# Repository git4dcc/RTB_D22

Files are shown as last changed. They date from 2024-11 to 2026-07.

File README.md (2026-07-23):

# RTB_D22




My Homebrew [D22](https://rtb4dcc.de/hardware/decoder/d22/) decoder is a double sided mobile decoder with Plux16 connector. The decoder is designed to integrate into the [RTB](https://rtb4dcc.de/concept/) digital control infrastructure.

<details>
<summary>See also</summary>

- [RTB_D12 - custom](/../../../../RTB_D12) (Fleischmann V100)
- [RTB_D13 - custom](/../../../../git4dcc/RTB_D13) (Minitrix coach)
- [RTB_D15 - custom](/../../../../git4dcc/RTB_D15) (Minitrix V160)
- [RTB_D16 - NEM651](/../../../../git4dcc/RTB_D16)
- [RTB_D20 - NEM651](/../../../../git4dcc/RTB_D20)
- [RTB_D21 - Next18](/../../../../git4dcc/RTB_D21)
- [RTB_D23 - NEM652](/../../../../git4dcc/RTB_D23)

</details>

<details>
<summary>User Guides</summary>

- User Guide - DE
- [User Guide - EN](https://rtb4dcc.de/rtb_decoder_reference_en/)

</details>

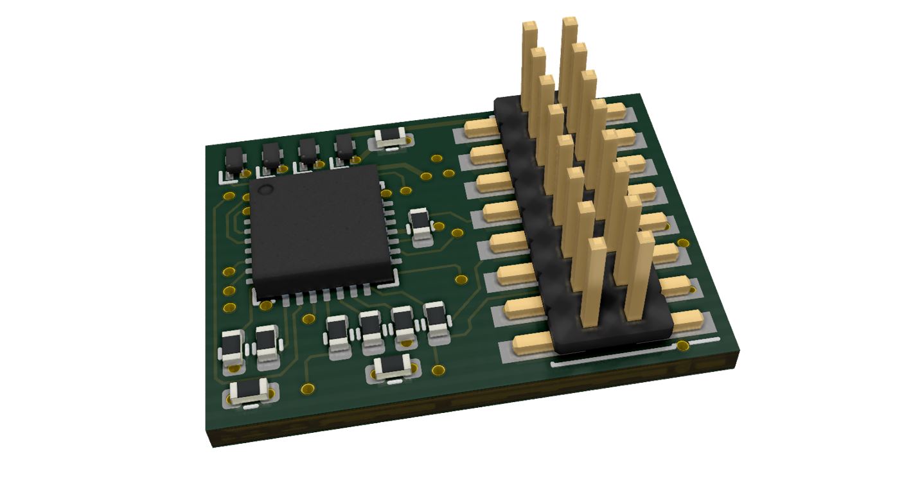
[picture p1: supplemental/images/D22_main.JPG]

<br>

## Decoder features,
- **Plux16** connector
- **DCC**
  - DCC-A automatic logon
  - DCC-R protocol extension
  - Service Mode Programming
- **Railcom**
  - Channel 1/2
  - POM, xPOM
  - DYN: Speed, QoS, Track-voltage, Motor-current, AUX-current, Temp, Distance travelled
- Double sided
- Dimension: 15 x 11 mm
- 7-20V track voltage
- heartbeat LED
- adjustable max motor current (default 300mA)
- adjustable max AUX current (default 500mA)
- over temp protection
- Function output: LF/LR (dimmable, 1.4kHz) open drain
- Function output: AUX1/AUX2 (dimmable, 1.4kHz) open drain
- Function output: AUX3/AUX4 logic level (3.3V) using LS A/B ports
- Function output: AUX5/AUX6 logic level (3.3V) or ZBCLK/ZBDAT (3.3V)
- optional external buffer capacitor
- <10mA idle power consumption
- Firmware update over main tracks via DCC-R protocol

# Hardware
The current PCB layout uses SMD footprints with 0.5mm pitch and 0402 parts. Reflow soldering is mandatory whereas handsoldering near to impossible.

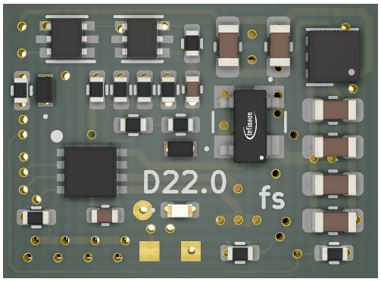
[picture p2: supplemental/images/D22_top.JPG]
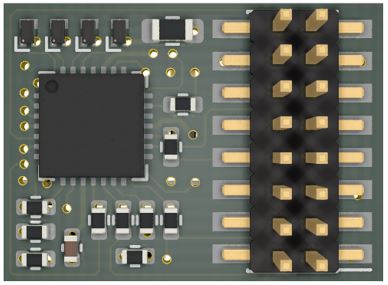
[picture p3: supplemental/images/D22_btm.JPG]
   

## PCB
- 6-layer PCB, FR4, 15 x 11 x 0.8mm (double sided)
- CPU: AVR64DD28
- Motor bridge: DRV8231

## Kicad
[Schematic](doc/D22_schematic.pdf) | [Layout](doc/D22_layout.pdf) | [Gerber](production)

<details>
<summary>Dependency</summary>
<br>

:yellow_circle: Requires my Kicad project library [RTB_SamacSys](https://github.com/git4dcc/RTB_SamacSys) in the same directory tree.

</details>

## Firmware
Filename structure: { **pcb** }{ **code** }{ **version** }.hex

Example: **D22F0001**.hex

| | Description |
| --- | --- |
| **pcb** | Name of matching hardware (**D22**) |
| **code** | Type of code contained (**R**=rom, **B**=bootloader, **F**=flash, **U**=bld update, **P**=UPDI factory code) |
| **version** | Release version (**####**) |

[Firmware files](firmware)

## UPDI
The fuse settings as well as the P-code (D22Pxxxx.hex) has to be installed by using UPDI.<br>
Connecting the decoder via its track pins to a 5V(DC) power supply will boot its CPU. This way, its easy to program the fuses and flash.

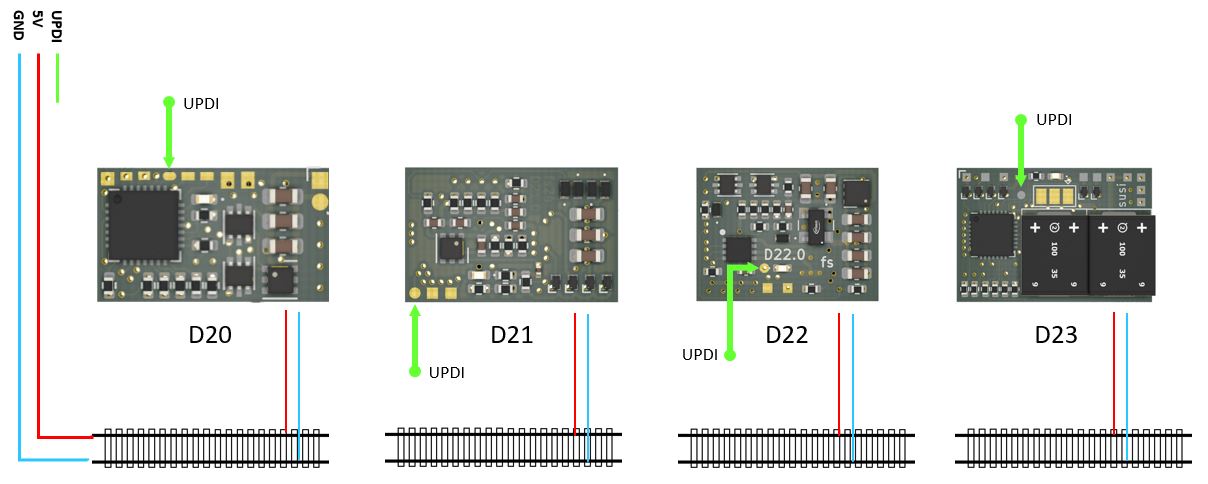
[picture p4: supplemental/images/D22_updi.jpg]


<details>
<summary>Details</summary>

| Fuse Setting | P-code Install |
| --- | --- |
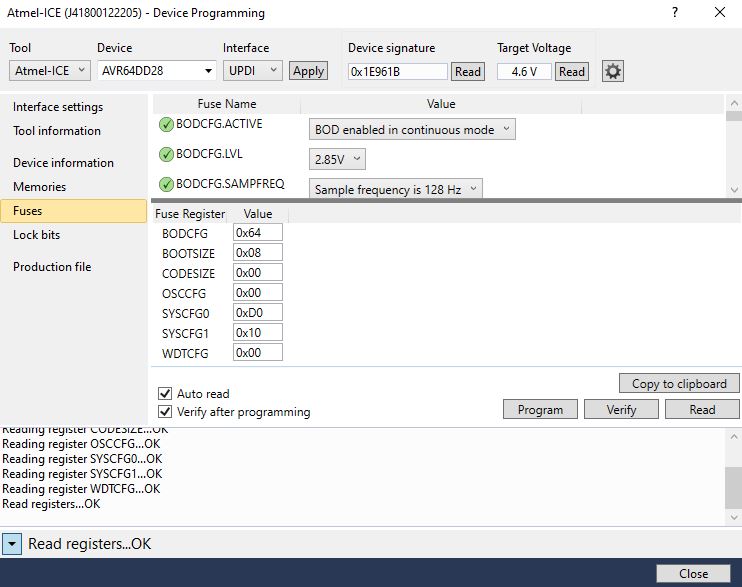
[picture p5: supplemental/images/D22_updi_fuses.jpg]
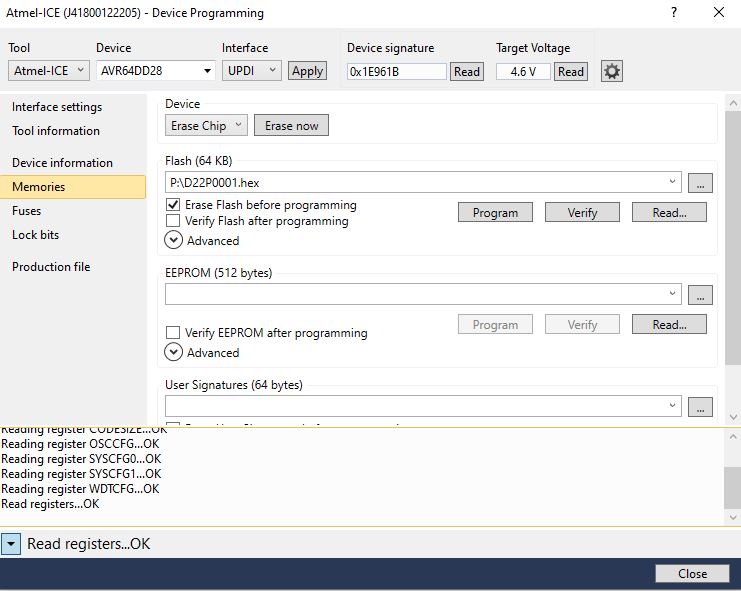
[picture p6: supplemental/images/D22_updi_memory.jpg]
|||

</details>

# Images
| top | bottom |
| --- | --- |
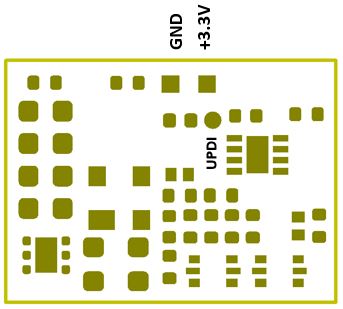
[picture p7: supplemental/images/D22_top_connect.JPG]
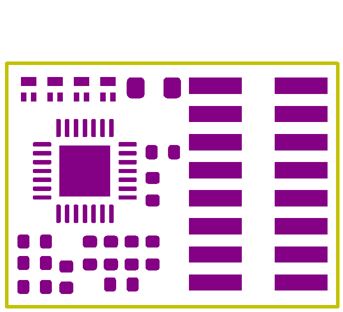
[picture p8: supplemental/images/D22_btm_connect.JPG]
|  |  |

# YouTube
Some YouTubes to see the D22 decoder in action.<br><br>
[](https://youtu.be/aH7pGpX5ZGo)
[](https://youtu.be/Ebl8b5DK1Gw)

This project is intended for hobby use only and is distributed in accordance with the Apache License 2.0 agreement.

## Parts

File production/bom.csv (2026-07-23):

Designator | Footprint | Quantity | Value | LCSC Part #
C1, C2 | 0603 | 2 | 10u/25V | C96446
C10, C8 | 0402 | 2 | 100n/50V | C307331
C3, C5 | 0603 | 2 | 22u/6V | C59461
C6 | 0402 | 1 | 1u/50V | C52923
D1, D2, D4 | SM5819L2TP | 3 | SM5819L2-TP | C6297199
D3 | 0402 | 1 | LED | C130724
D8 | BF998215 | 1 | BAS3007ARPPE6327HTSA1 | C6430958
IC1 | QFN-28-1EP_4x4mm_P0.4mm_EP2.3x2.3mm | 1 | AVR64DD28-I_STX | C5156221
IC2 | WSON-6-1EP_2x2mm_P0.65mm_EP1x1.6mm | 1 | NCP730BMT500TBG | C892822
IC3 | SON50P200X200X80-9N | 1 | DRV8231ADSGR | C5139865
IC4 | WSON-6-1EP_2x2mm_P0.65mm_EP1x1.6mm | 1 | NCP730BMT1500TBG | C892817
J1 | PinHeader_2x08_P1.27mm_Vertical_SMD | 1 | Conn_02x08_Counter_Clockwise
J2 | Solder 0.8 x 0.5 | 1 | Conn_01x01
Q1 | SOT-666 | 1 | BC847BDW1 | C455062
Q2 | SOT-666 | 1 | BC857BDW1 | C282521
Q3, Q4, Q5, Q6 | Diodes_DFN1006-3 | 4 | PMZB200UNEYL | C547292
R1, R15, R17, R2 | 0402 | 4 | 33k | C25779
R10, R9 | 0402 | 2 | 9.1k | C163450
R11, R12, R24, R5, R6 | 0402 | 5 | 10k | C25744
R13 | 0402 | 1 | 1k | C11702
R14, R7, R8 | 0402 | 3 | 220k | C25767
R16, R18 | 0402 | 2 | 12k | C25752
R19 | 0603 | 1 | 1 | C22936
R20 | 0402 | 1 | 47k | C25792
R21, R22 | 0402 | 2 | 470 | C25117
R23 | 0603 | 1 | 100 | C22775
R3 | 0402 | 1 | 3.3k | C25900
R4 | 0402 | 1 | 22 | C25092

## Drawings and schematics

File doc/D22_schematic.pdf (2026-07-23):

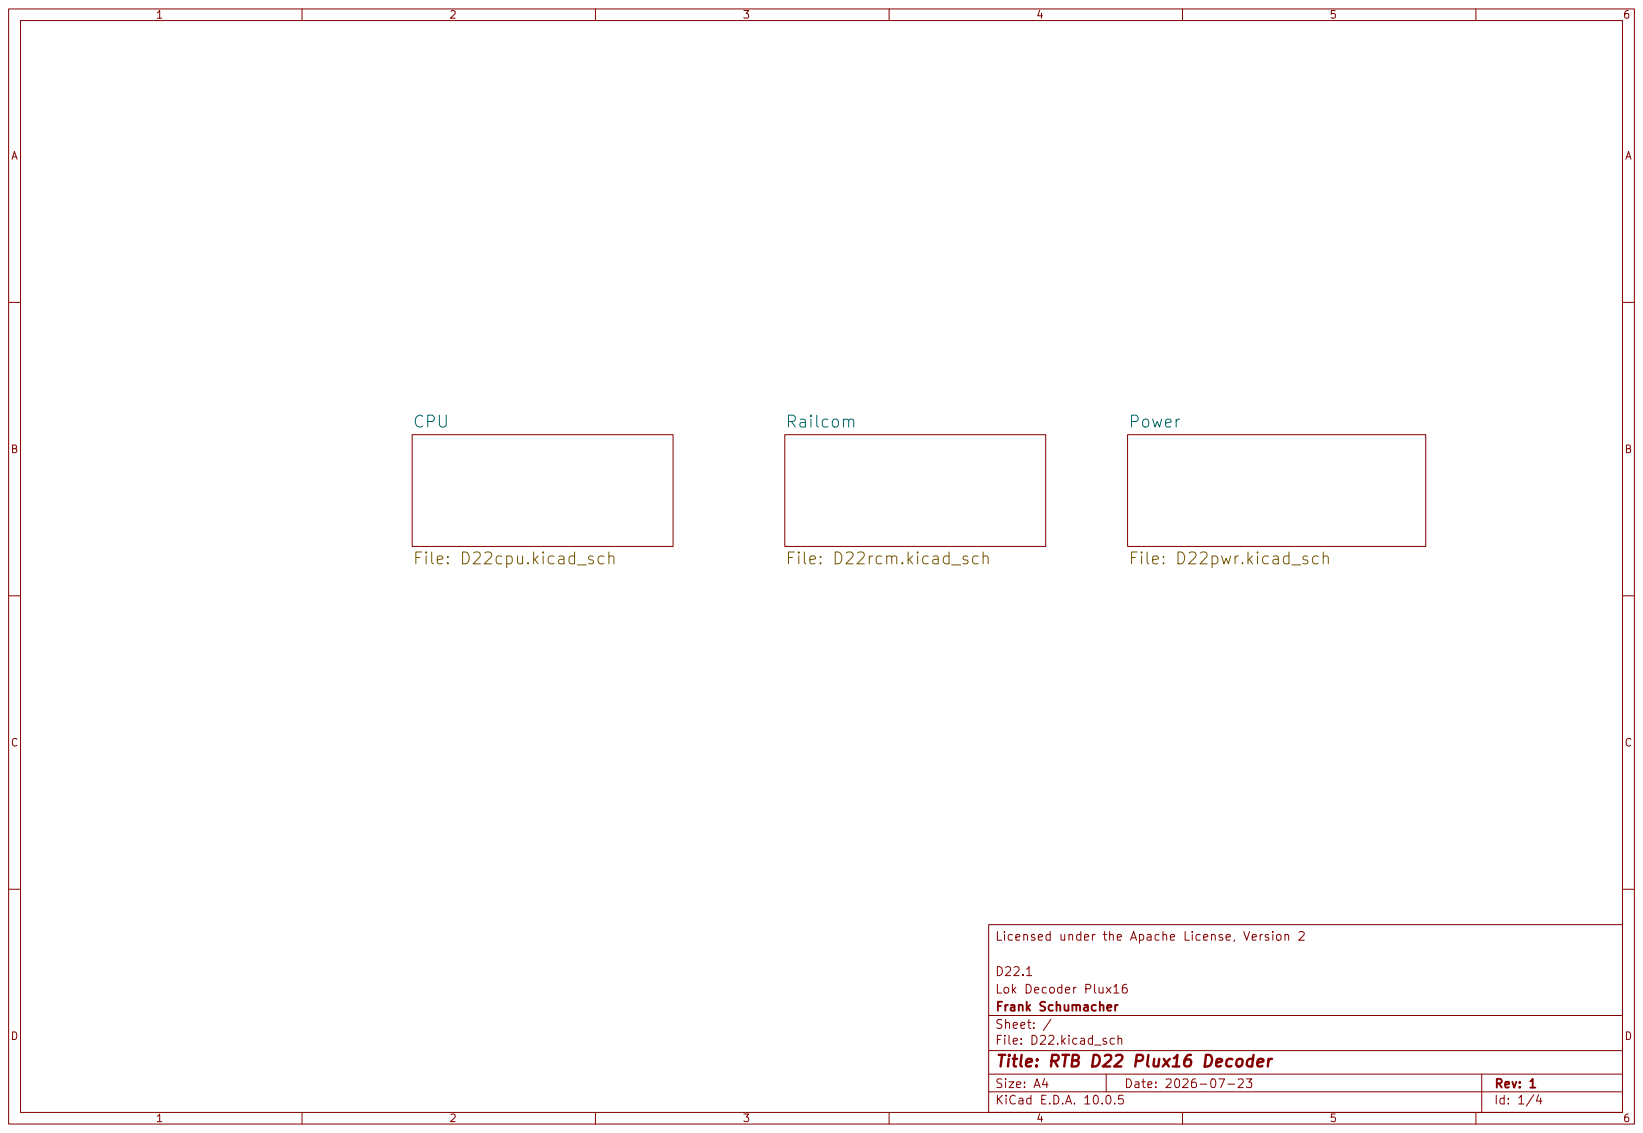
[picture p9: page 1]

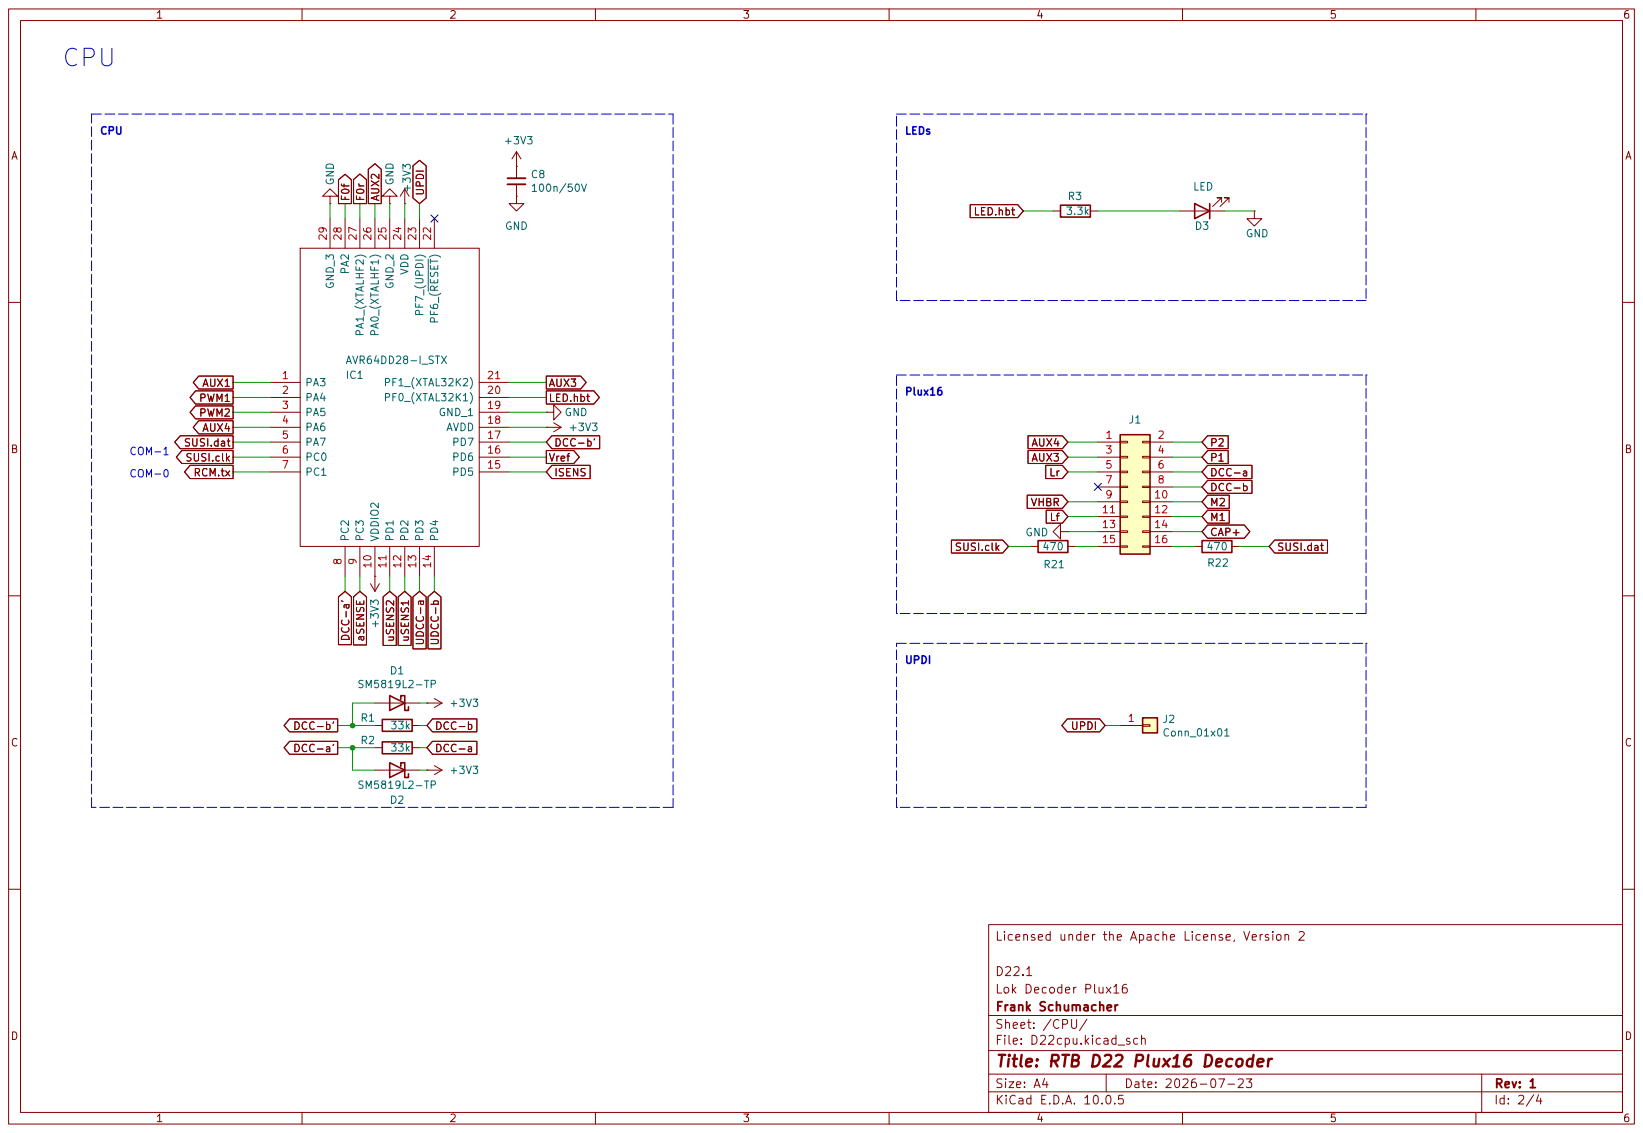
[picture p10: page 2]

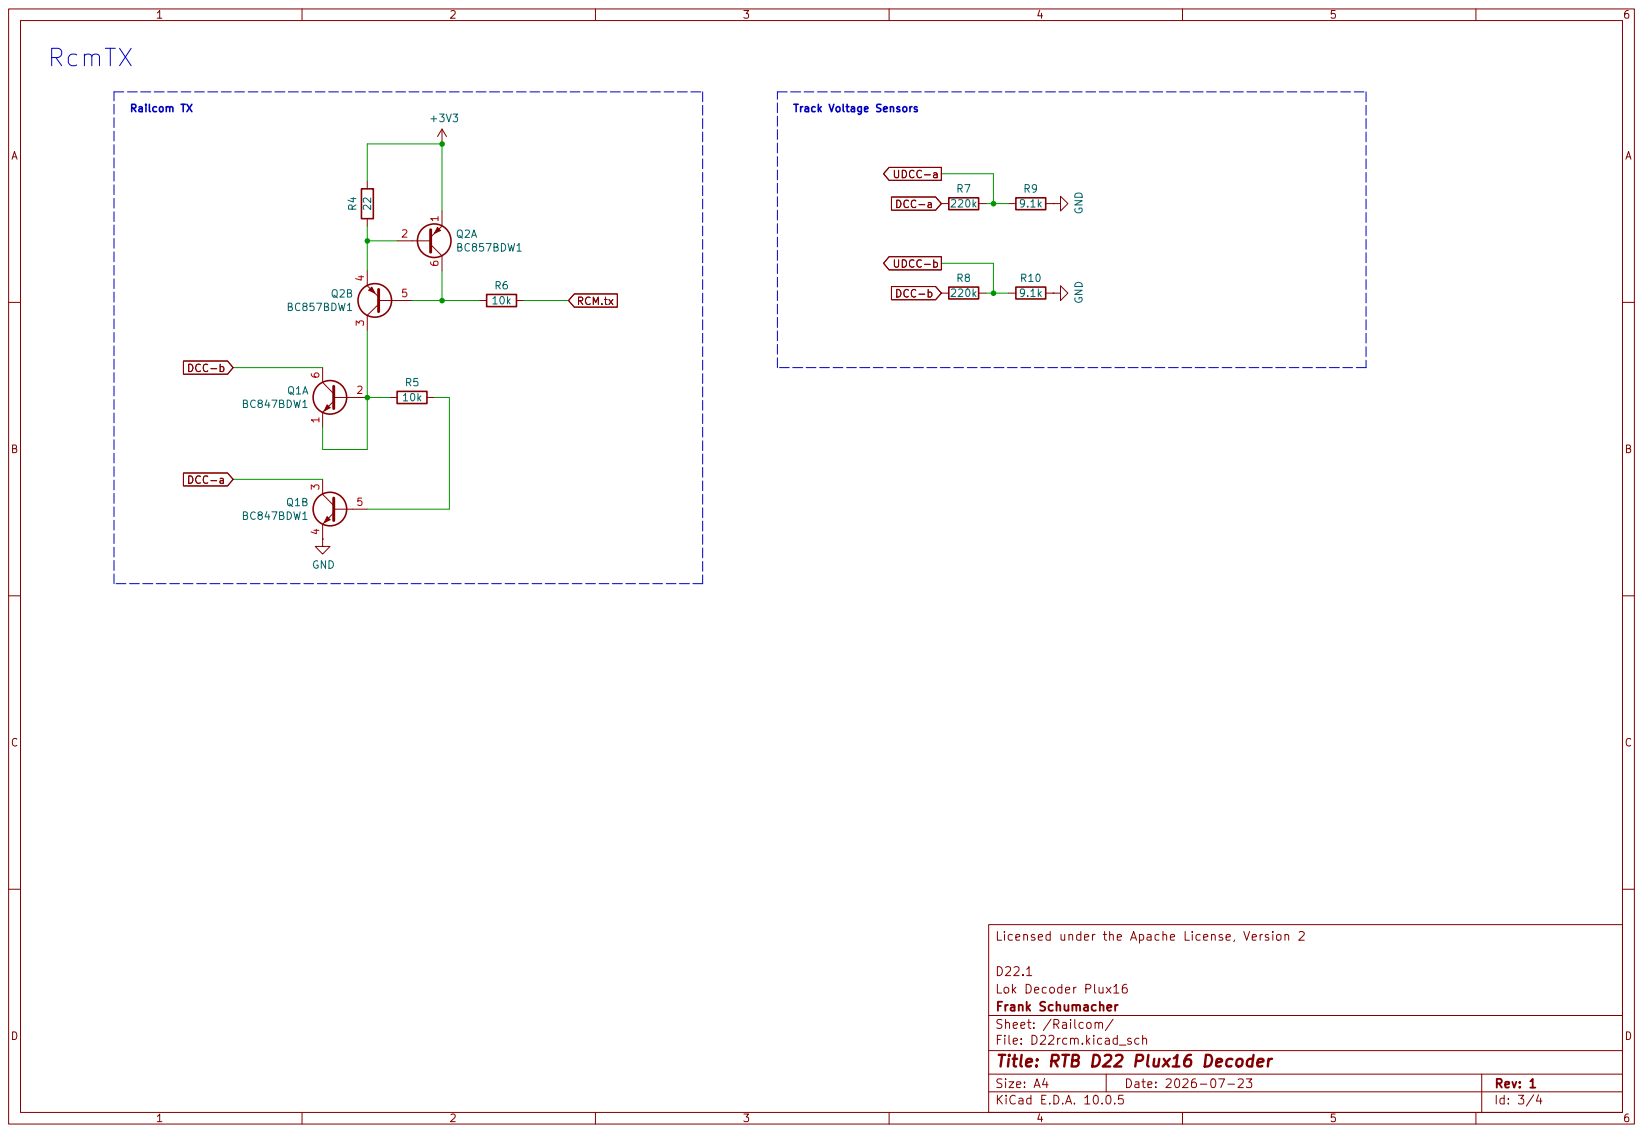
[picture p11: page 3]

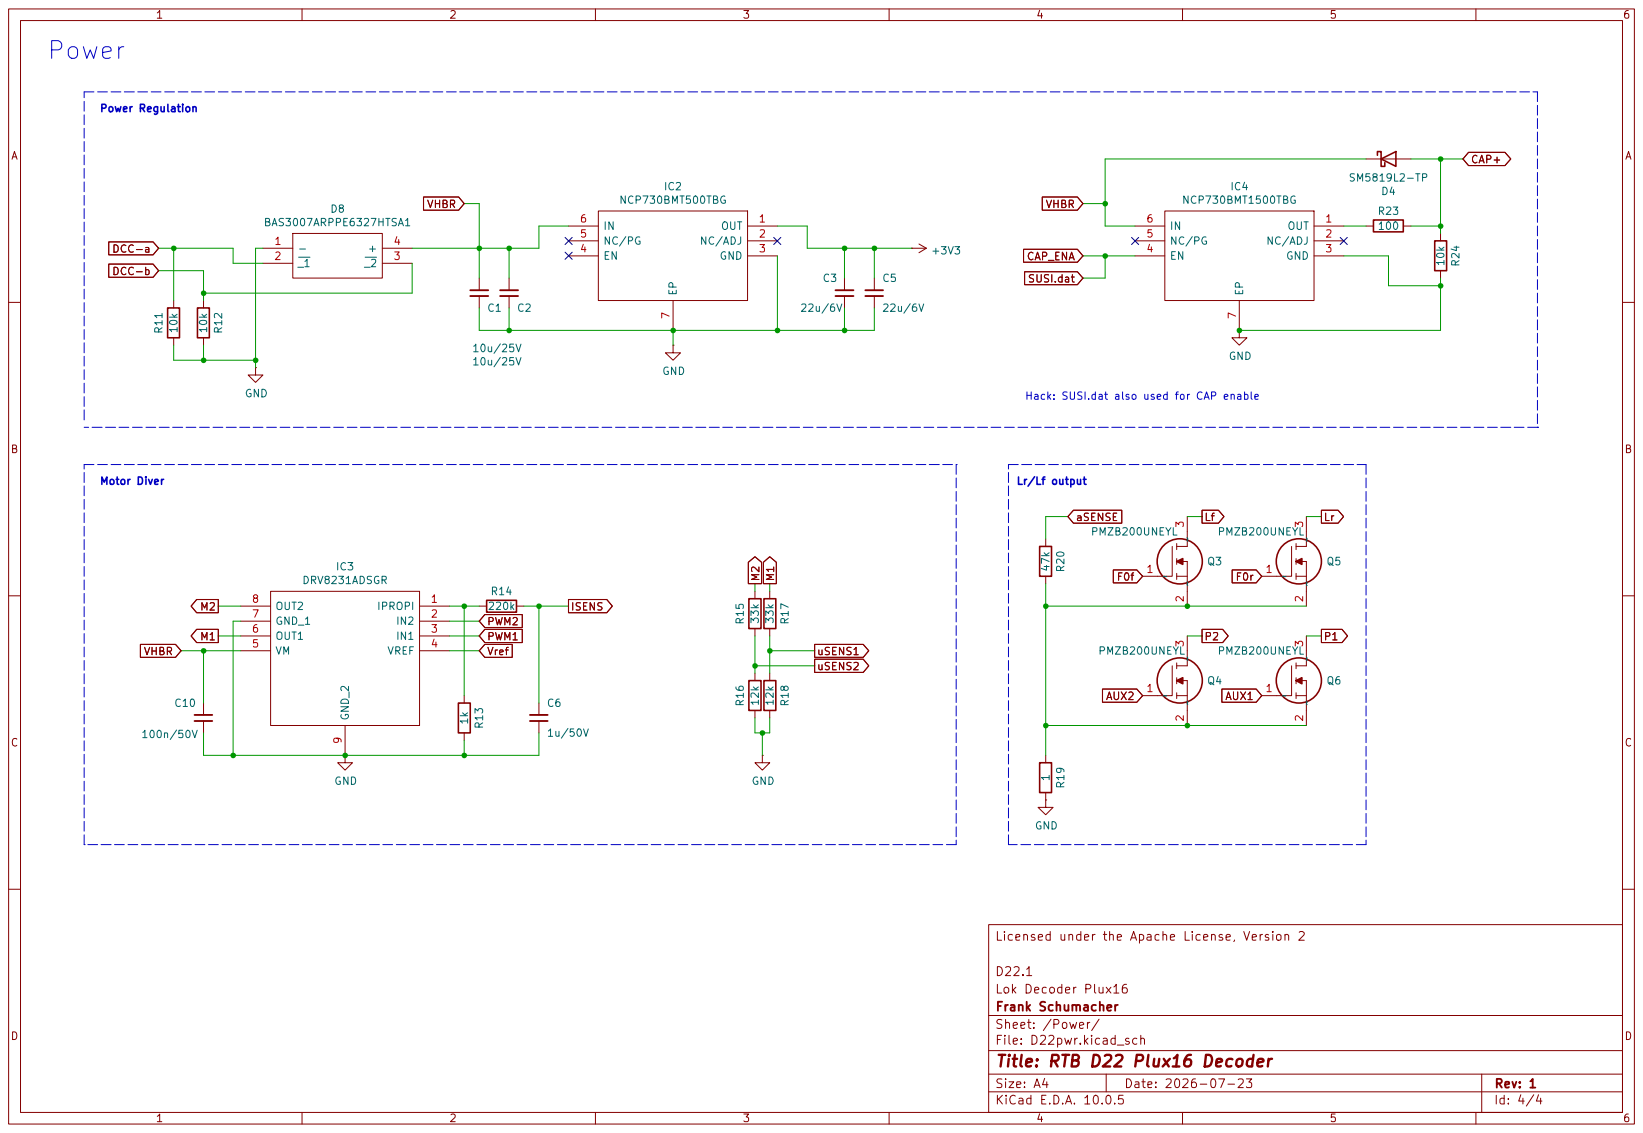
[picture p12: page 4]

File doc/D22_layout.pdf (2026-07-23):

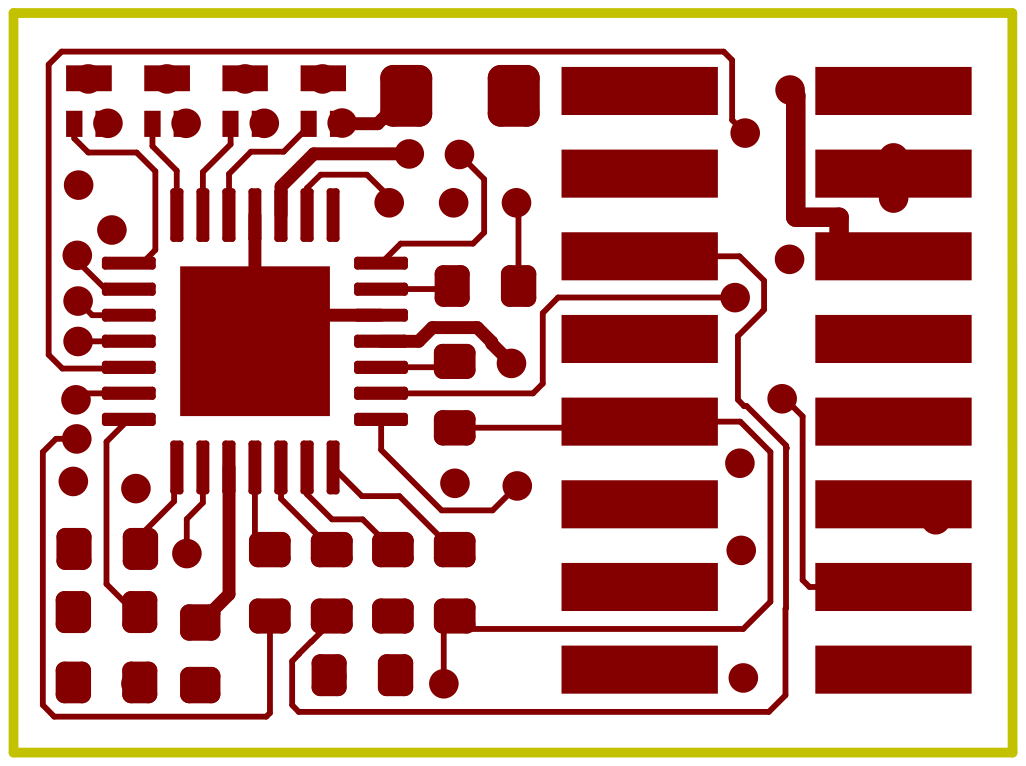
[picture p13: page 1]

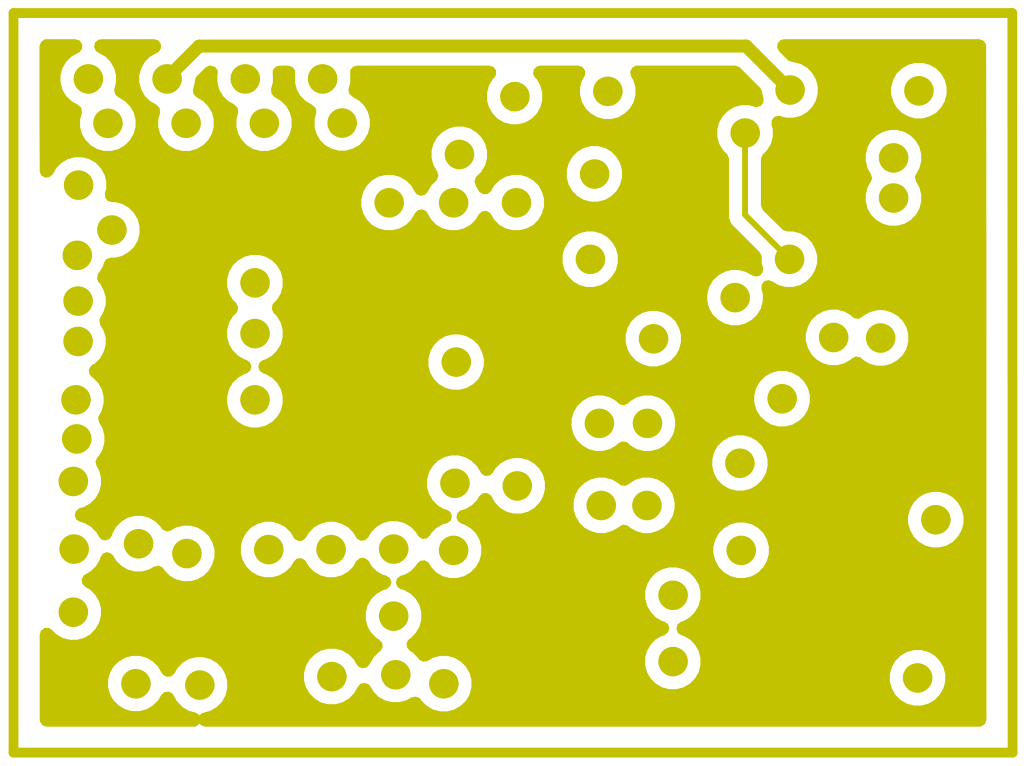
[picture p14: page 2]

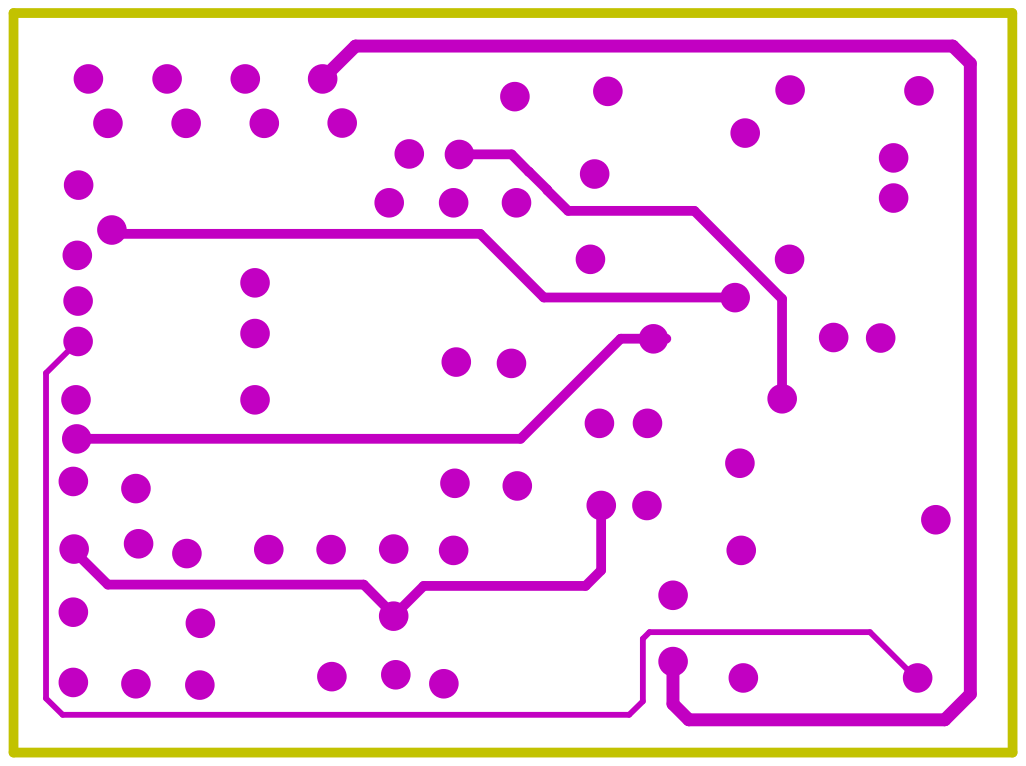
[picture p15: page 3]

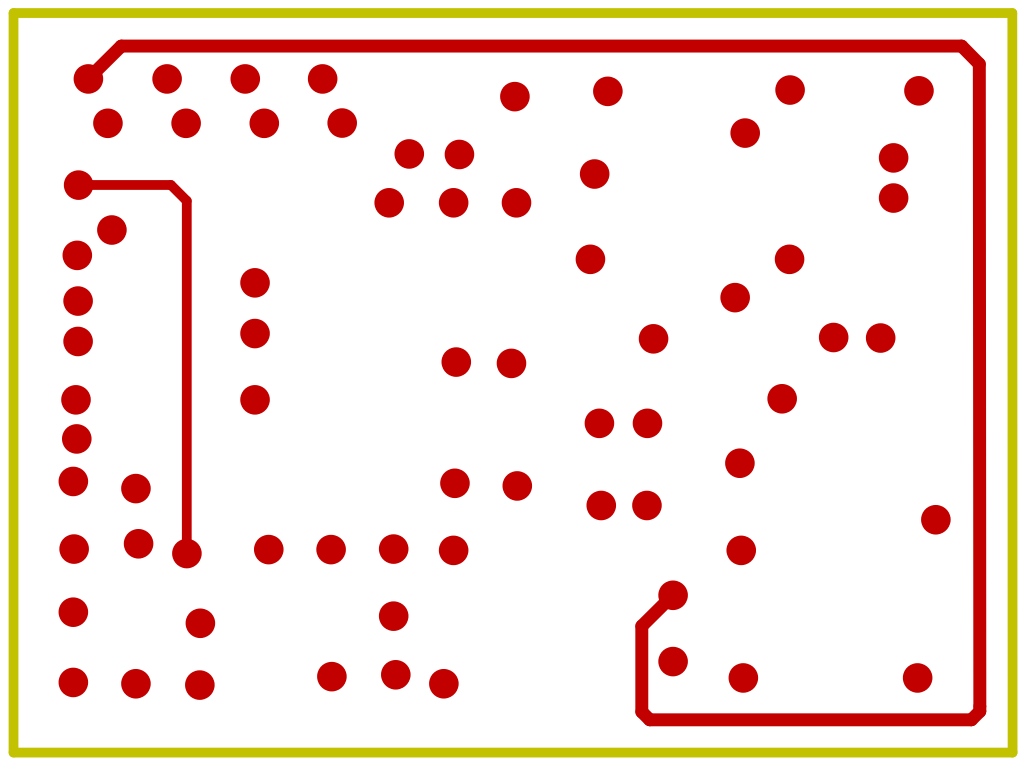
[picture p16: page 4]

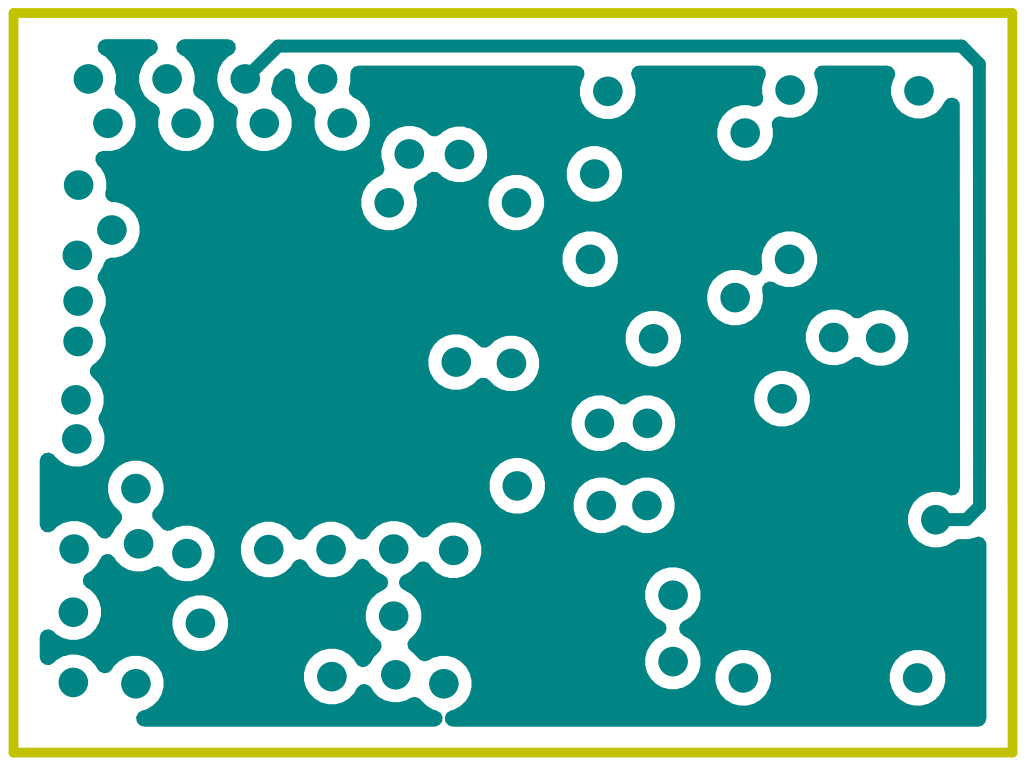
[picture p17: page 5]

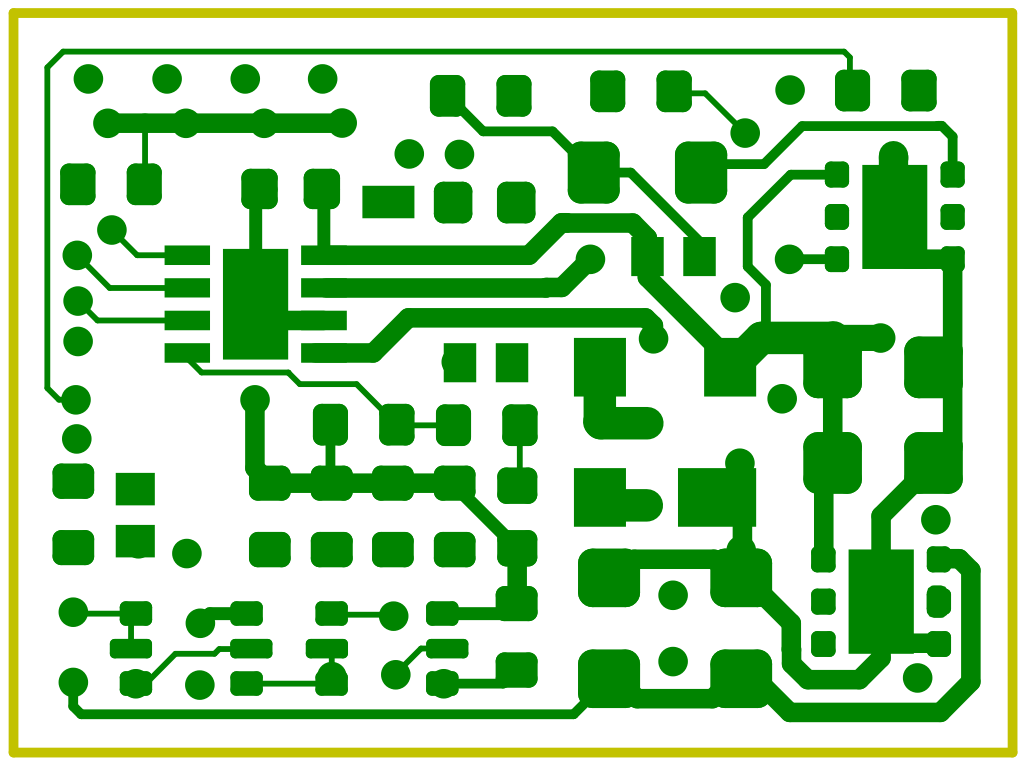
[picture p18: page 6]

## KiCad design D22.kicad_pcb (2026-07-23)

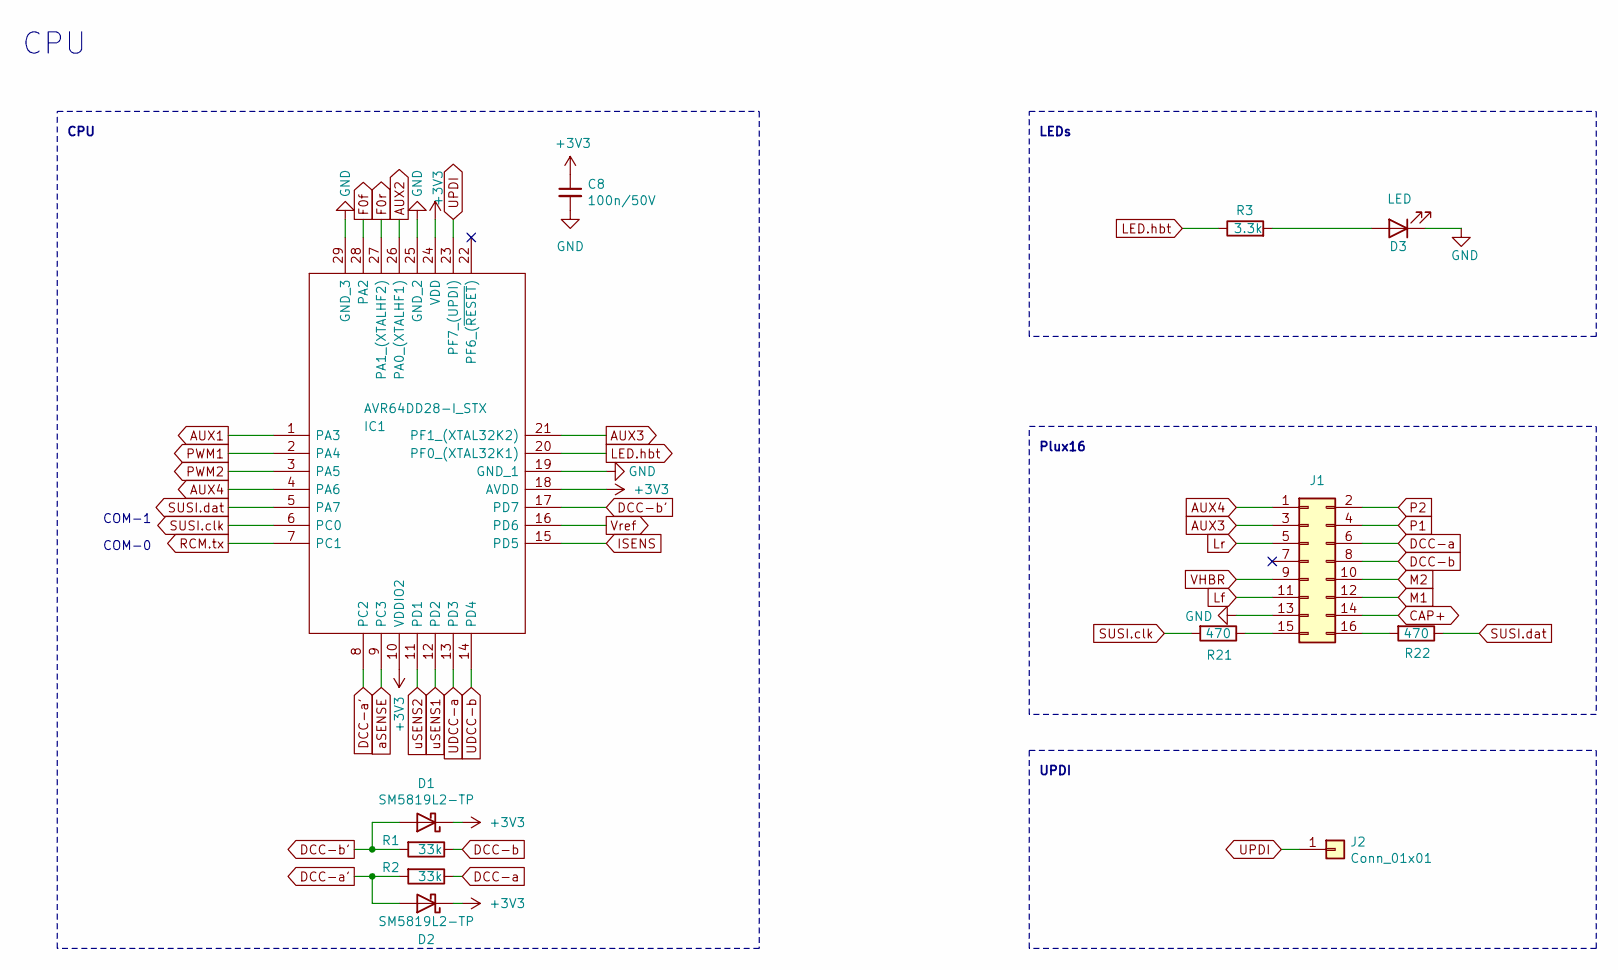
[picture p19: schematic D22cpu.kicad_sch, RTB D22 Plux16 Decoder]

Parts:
C8: 100n/50V; C_0402_1005Metric; LCSC Part # C307331
D1, D2: SM5819L2-TP; SM5819L2TP; LCSC Part # C6297199
D3: LED; LED_0402_1005Metric; LCSC Part # C130724
IC1: AVR64DD28-I_STX; QFN-28-1EP_4x4mm_P0.4mm_EP2.3x2.3mm; LCSC Part # C5156221
J1: Conn_02x08_Counter_Clockwise; PinHeader_2x08_P1.27mm_Vertical_SMD
J2: Conn_01x01; Solder 0.8 x 0.5
R1, R2: 33k; R_0402_1005Metric; LCSC Part # C25779
R3: 3.3k; R_0402_1005Metric; LCSC Part # C25900
R21, R22: 470; R_0402_1005Metric; LCSC Part # C25117

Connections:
+3V3: C8.1, D1.1 (K), D2.1 (K), IC1.10 (VDDIO2), IC1.18 (AVDD), IC1.24 (VDD); also elsewhere on the board
AUX1: IC1.1 (PA3); also elsewhere on the board
AUX2: IC1.26 (PA0_(XTALHF1)); also elsewhere on the board
AUX3: IC1.21 (PF1_(XTAL32K2)), J1.3
AUX4: IC1.4 (PA6), J1.1
CAP+: J1.14; also elsewhere on the board
CAP_ENA: IC1.5 (PA7), R22.1; also elsewhere on the board
DCC-a: J1.6, R2.1; also elsewhere on the board
DCC-a': D2.2 (A), IC1.8 (PC2), R2.2
DCC-b: J1.8, R1.1; also elsewhere on the board
DCC-b': D1.2 (A), IC1.17 (PD7), R1.2
F0f: IC1.28 (PA2); also elsewhere on the board
F0r: IC1.27 (PA1_(XTALHF2)); also elsewhere on the board
GND: C8.2, D3.1 (K), IC1.19 (GND_1), IC1.25 (GND_2), IC1.29 (GND_3), J1.13; also elsewhere on the board
ISENS: IC1.15 (PD5); also elsewhere on the board
LED.hbt: IC1.20 (PF0_(XTAL32K1)), R3.1
Lf: J1.11; also elsewhere on the board
Lr: J1.5; also elsewhere on the board
M1: J1.12; also elsewhere on the board
M2: J1.10; also elsewhere on the board
unnamed: D3.2 (A), R3.2
unnamed: J1.15, R21.1
unnamed: J1.16, R22.2
P1: J1.4; also elsewhere on the board
P2: J1.2; also elsewhere on the board
PWM1: IC1.2 (PA4); also elsewhere on the board
PWM2: IC1.3 (PA5); also elsewhere on the board
RCM.tx: IC1.7 (PC1); also elsewhere on the board
SUSI.clk: IC1.6 (PC0), R21.2
UDCC-a: IC1.13 (PD3); also elsewhere on the board
UDCC-b: IC1.14 (PD4); also elsewhere on the board
UPDI: IC1.23 (PF7_(UPDI)), J2.1 (Pin_1_1)
VHBR: J1.9; also elsewhere on the board
Vref: IC1.16 (PD6); also elsewhere on the board
aSENSE: IC1.9 (PC3); also elsewhere on the board
uSENS1: IC1.12 (PD2); also elsewhere on the board
uSENS2: IC1.11 (PD1); also elsewhere on the board

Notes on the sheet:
Plux16
COM-0
COM-1
CPU
LEDs
UPDI

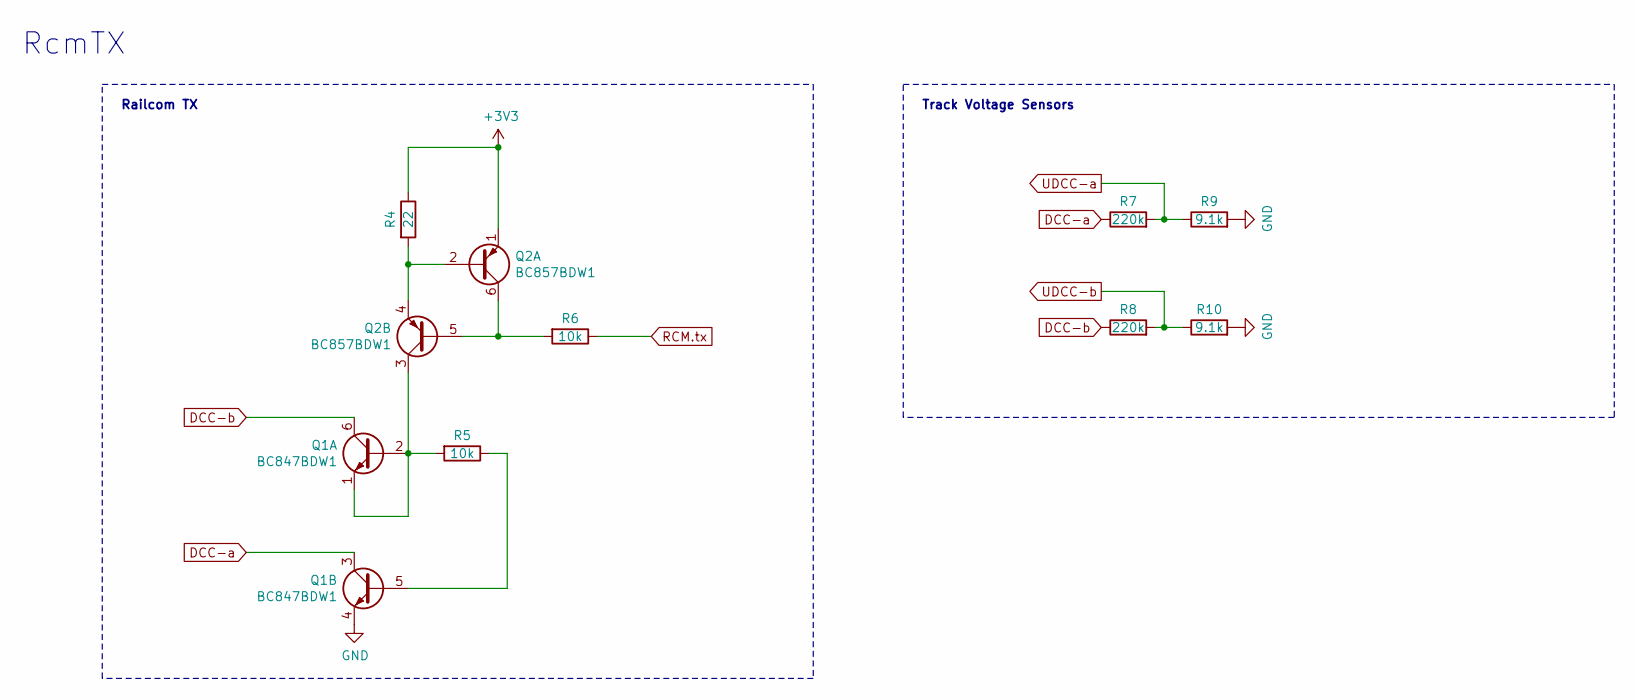
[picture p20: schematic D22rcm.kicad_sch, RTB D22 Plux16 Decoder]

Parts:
Q1: BC847BDW1; SOT-666; LCSC Part # C455062
Q2: BC857BDW1; SOT-666; LCSC Part # C282521
R4: 22; R_0402_1005Metric; LCSC Part # C25092
R5, R6: 10k; R_0402_1005Metric; LCSC Part # C25744
R7, R8: 220k; R_0402_1005Metric; LCSC Part # C25767
R9, R10: 9.1k; R_0402_1005Metric; LCSC Part # C163450

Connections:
+3V3: Q2.1 (E1), R4.1; also elsewhere on the board
DCC-a: Q1.3 (C2), R7.1; also elsewhere on the board
DCC-b: Q1.6 (C1), R8.1; also elsewhere on the board
GND: Q1.4 (E2), R9.2, R10.2; also elsewhere on the board
unnamed: Q1.1 (E1), Q1.2 (B1), Q2.3 (C2), R5.2
unnamed: Q1.5 (B2), R5.1
unnamed: Q2.2 (B1), Q2.4 (E2), R4.2
unnamed: Q2.5 (B2), Q2.6 (C1), R6.2
RCM.tx: R6.1; also elsewhere on the board
UDCC-a: R7.2, R9.1; also elsewhere on the board
UDCC-b: R8.2, R10.1; also elsewhere on the board

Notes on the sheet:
Railcom TX
Track Voltage Sensors
RcmTX

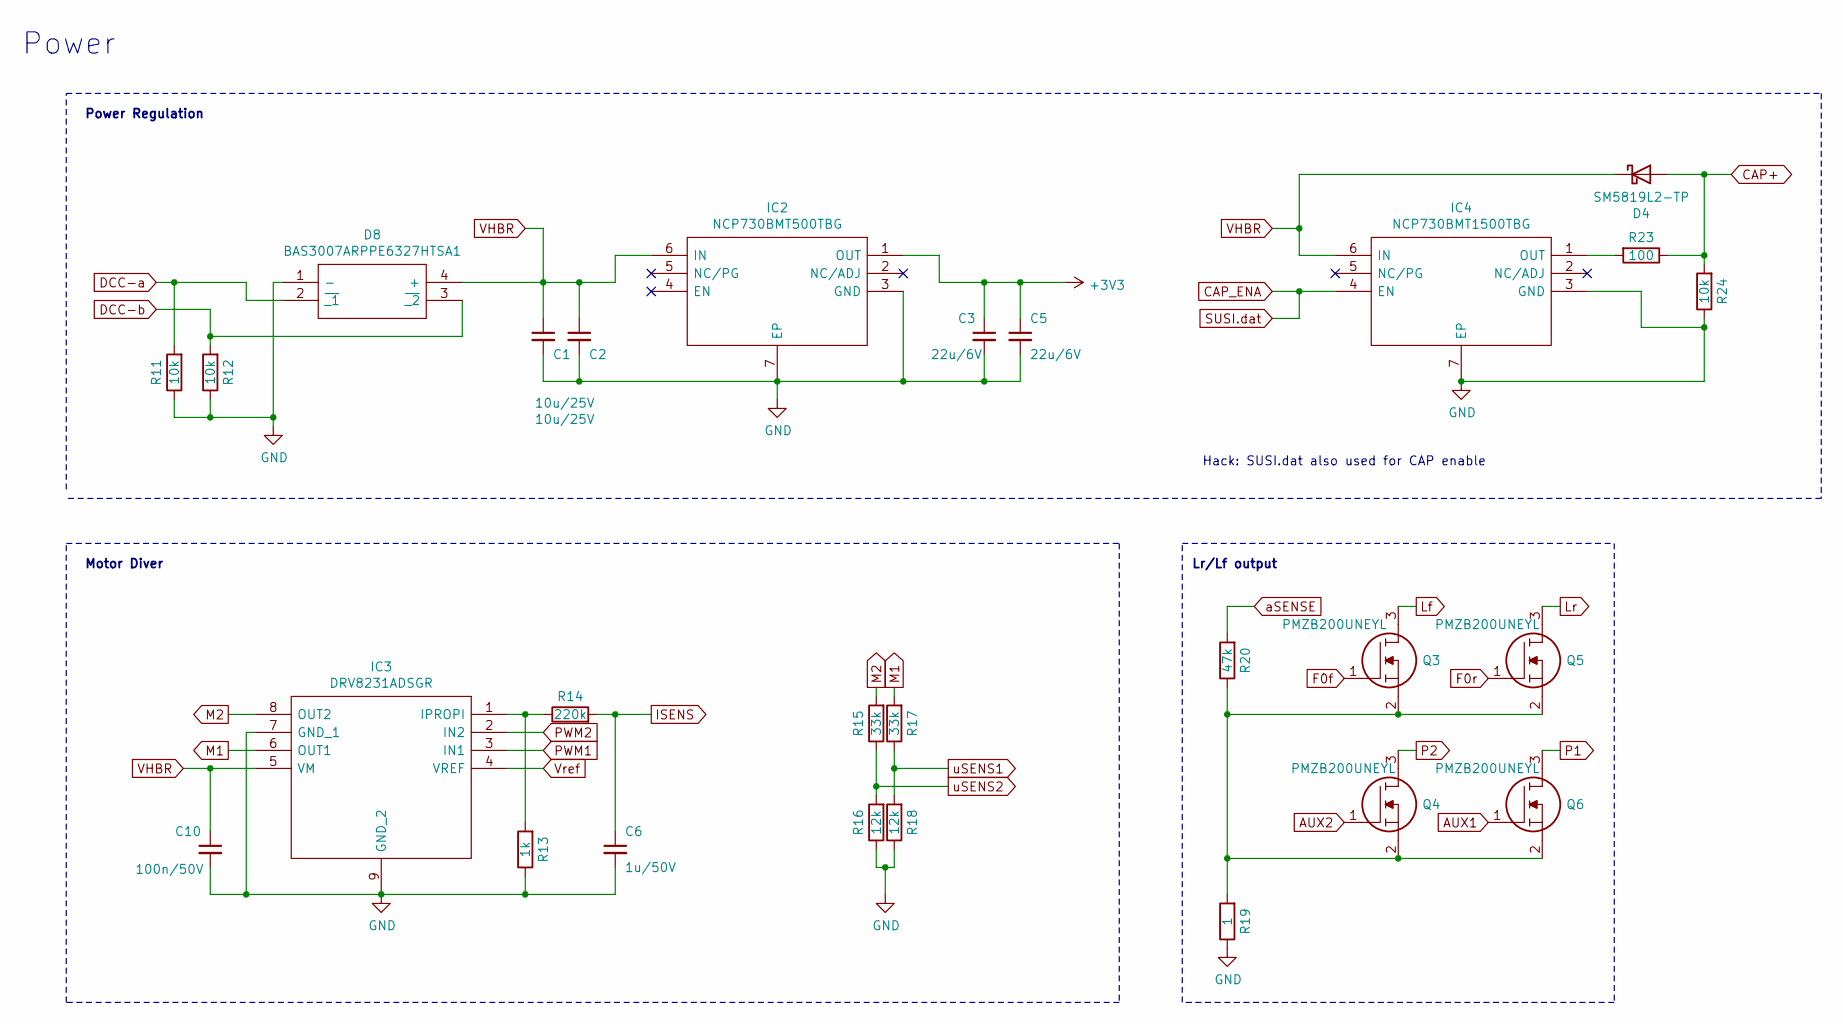
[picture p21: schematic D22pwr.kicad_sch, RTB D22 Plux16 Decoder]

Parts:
C1, C2: 10u/25V; C_0603_1608Metric; LCSC Part # C96446
C3, C5: 22u/6V; C_0603_1608Metric; LCSC Part # C59461
C6: 1u/50V; C_0402_1005Metric; LCSC Part # C52923
C10: 100n/50V; C_0402_1005Metric; LCSC Part # C307331
D4: SM5819L2-TP; SM5819L2TP; LCSC Part # C6297199
D8: BAS3007ARPPE6327HTSA1; BF998215; LCSC Part # C6430958
IC2: NCP730BMT500TBG; WSON-6-1EP_2x2mm_P0.65mm_EP1x1.6mm; LCSC Part # C892822
IC3: DRV8231ADSGR; SON50P200X200X80-9N; LCSC Part # C5139865
IC4: NCP730BMT1500TBG; WSON-6-1EP_2x2mm_P0.65mm_EP1x1.6mm; LCSC Part # C892817
Q3, Q4, Q5, Q6: PMZB200UNEYL; Diodes_DFN1006-3; LCSC Part # C547292
R11, R12, R24: 10k; R_0402_1005Metric; LCSC Part # C25744
R13: 1k; R_0402_1005Metric; LCSC Part # C11702
R14: 220k; R_0402_1005Metric; LCSC Part # C25767
R15, R17: 33k; R_0402_1005Metric; LCSC Part # C25779
R16, R18: 12k; R_0402_1005Metric; LCSC Part # C25752
R19: 1; R_0603_1608Metric; LCSC Part # C22936
R20: 47k; R_0402_1005Metric; LCSC Part # C25792
R23: 100; R_0603_1608Metric; LCSC Part # C22775

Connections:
+3V3: C3.1, C5.1, IC2.1 (OUT); also elsewhere on the board
AUX1: Q6.1; also elsewhere on the board
AUX2: Q4.1; also elsewhere on the board
CAP+: D4.2 (A), R23.1, R24.2; also elsewhere on the board
CAP_ENA: IC4.4 (EN); also elsewhere on the board
DCC-a: D8.2 (~_1), R11.2; also elsewhere on the board
DCC-b: D8.3 (~_2), R12.2; also elsewhere on the board
F0f: Q3.1; also elsewhere on the board
F0r: Q5.1; also elsewhere on the board
GND: C1.2, C2.2, C3.2, C5.2, C6.2, C10.2, D8.1 (-), IC2.3 (GND), IC2.7 (EP), IC3.7 (GND_1), IC3.9 (GND_2), IC4.3 (GND), IC4.7 (EP), R11.1, R12.1, R13.1, R16.1, R18.1, R19.1, R24.1; also elsewhere on the board
ISENS: C6.1, R14.2; also elsewhere on the board
Lf: Q3.3; also elsewhere on the board
Lr: Q5.3; also elsewhere on the board
M1: IC3.6 (OUT1), R17.2; also elsewhere on the board
M2: IC3.8 (OUT2), R15.2; also elsewhere on the board
unnamed: IC3.1 (IPROPI), R13.2, R14.1
unnamed: IC4.1 (OUT), R23.2
unnamed: Q3.2, Q4.2, Q5.2, Q6.2, R19.2, R20.1
P1: Q6.3; also elsewhere on the board
P2: Q4.3; also elsewhere on the board
PWM1: IC3.3 (IN1); also elsewhere on the board
PWM2: IC3.2 (IN2); also elsewhere on the board
VHBR: C1.1, C2.1, C10.1, D4.1 (K), D8.4 (+), IC2.6 (IN), IC3.5 (VM), IC4.6 (IN); also elsewhere on the board
Vref: IC3.4 (VREF); also elsewhere on the board
aSENSE: R20.2; also elsewhere on the board
uSENS1: R17.1, R18.2; also elsewhere on the board
uSENS2: R15.1, R16.2; also elsewhere on the board

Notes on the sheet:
Power
Power Regulation
Motor Diver
Lr/Lf output
Hack: SUSI.dat also used for CAP enable

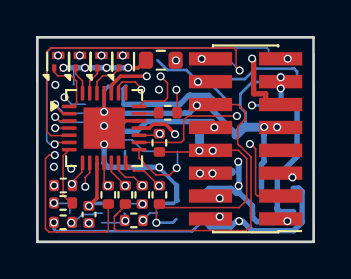
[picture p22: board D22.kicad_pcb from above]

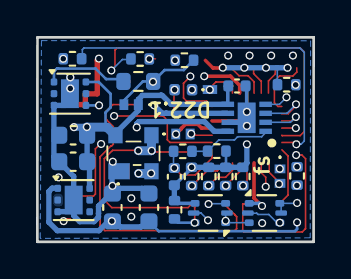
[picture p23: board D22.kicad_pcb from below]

Board: 6 copper layers, 15.3 x 11.4 mm, 48 parts (30 on the bottom side), 44 nets.

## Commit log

2025-07-31 add: fuses
    [D22.kicad_pcb, D22cpu.sch, D22pwr.sch]
2025-08-05 mod: led automation
2026-06-26 updated Kicad version
    [D22.kicad_pcb, D22.kicad_sch, D22cpu.kicad_sch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]
2026-07-09 mod: code cleanup
    [D22.kicad_pcb, D22.kicad_sch, D22.sch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]
2026-07-23 add: 15V LDO for backup cap
    [D22.kicad_pcb, D22.kicad_sch, D22cpu.kicad_sch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]

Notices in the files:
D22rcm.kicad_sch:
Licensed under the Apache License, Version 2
